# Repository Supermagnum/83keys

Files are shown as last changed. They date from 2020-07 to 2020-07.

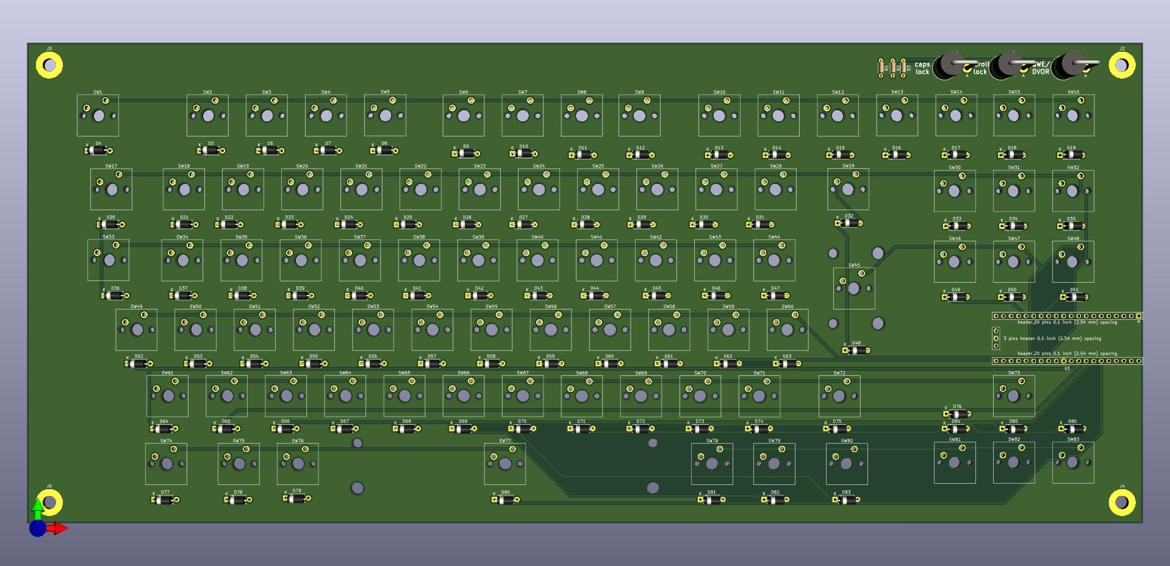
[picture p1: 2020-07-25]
Keyboard-ISO.jpg

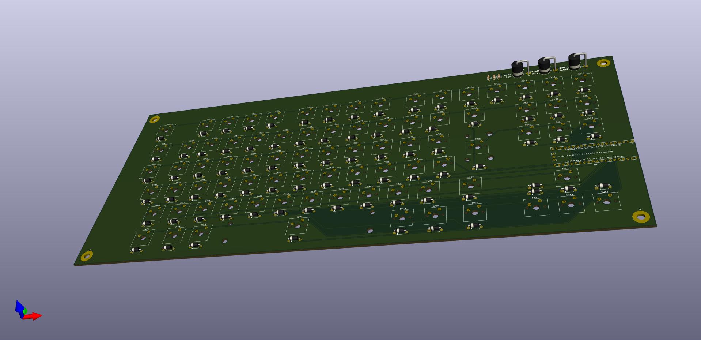
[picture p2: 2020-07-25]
Keyboard-ISO2.jpg

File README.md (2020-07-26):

# 83keys
A 83 key keyboard, Norwegian QWERTY/DVORAK ISO style.
It's of course possible to use other languages, as the MX cherry switches will accept keycaps with whatever language you need.

It uses 83 1N4148 diodes and three LED's for caps lock,scroll lock, and QWERTY/DVORAK.
It also needs pin headers that accepts the pins from a Teensy++2.0.

That makes it easy to replace the Teensy in the case that something goes wrong.
Since the Teensy++2.0 is mounted in a socket, there is no special training required because there are no need to solder any SMD components. 
I think that that makes it easier to mass produce because little training and special tools are required.

The keyboard layout is located here:
http://www.keyboard-layout-editor.com/#/gists/53284f72c23040b29def237b7399e567

Made using Kicad, that can be found here:
https://kicad-pcb.org/

All footprints for the components needed for the keyboard is included in this GitHub.
That excludes the Teensy++2.0 board and the components needed for it.

Kicad footprints for Teensy 
https://github.com/XenGi/teensy.pretty

Kicad schematic symbols of Teensy modules:
https://github.com/XenGi/teensy_library

QMK is here:
https://qmk.fm/

The handwire folder contains files necessary to make the bottom,top and switch plates for those who want to handwire the keyboard without using a PCB.
It should be compatible with Cherry Stabilizers. 

I hope that the Teensy socket is wired up correctly.
If not,please fork this repository and make the required changes.

Note: The diodes on the schematic diagram is wrong.

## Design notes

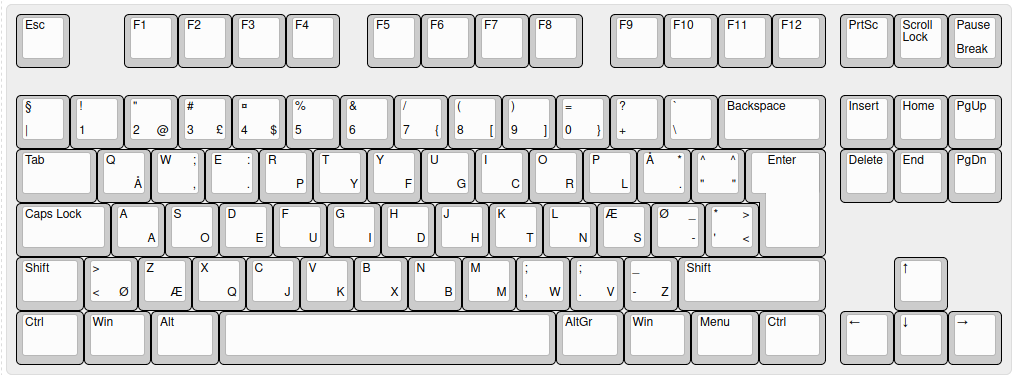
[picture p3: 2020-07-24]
layout.png

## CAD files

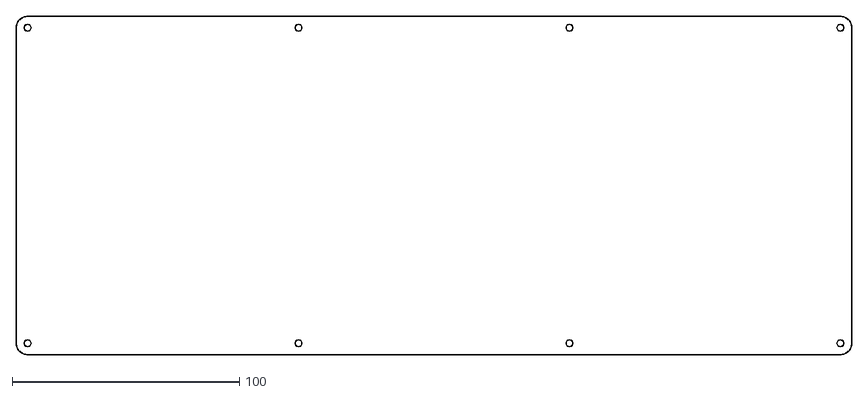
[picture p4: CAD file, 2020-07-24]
handwire/Plate_bottom.dxf
367.7 x 148.8

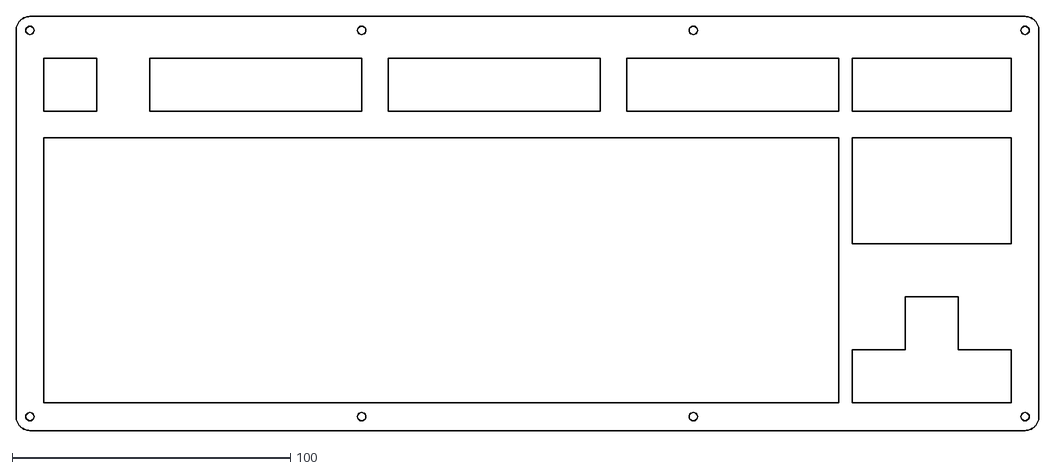
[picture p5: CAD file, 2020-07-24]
handwire/top.dxf
367.7 x 148.8

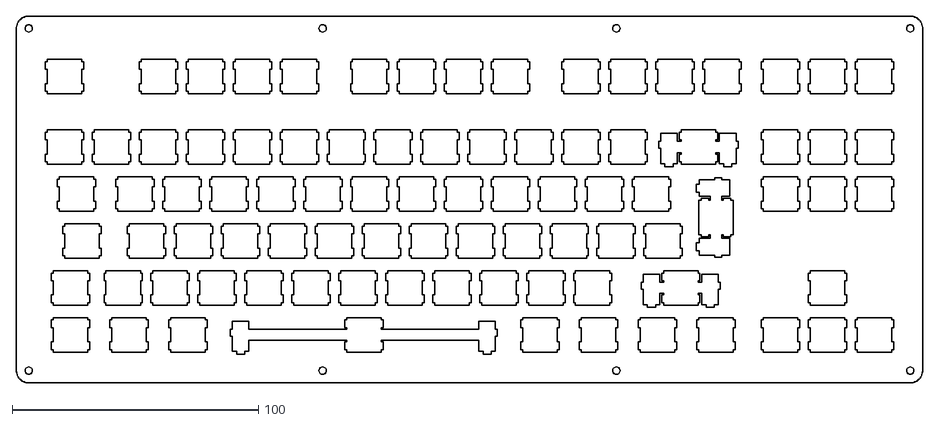
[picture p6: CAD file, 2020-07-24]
handwire/Plate_switch.dxf
367.7 x 148.8

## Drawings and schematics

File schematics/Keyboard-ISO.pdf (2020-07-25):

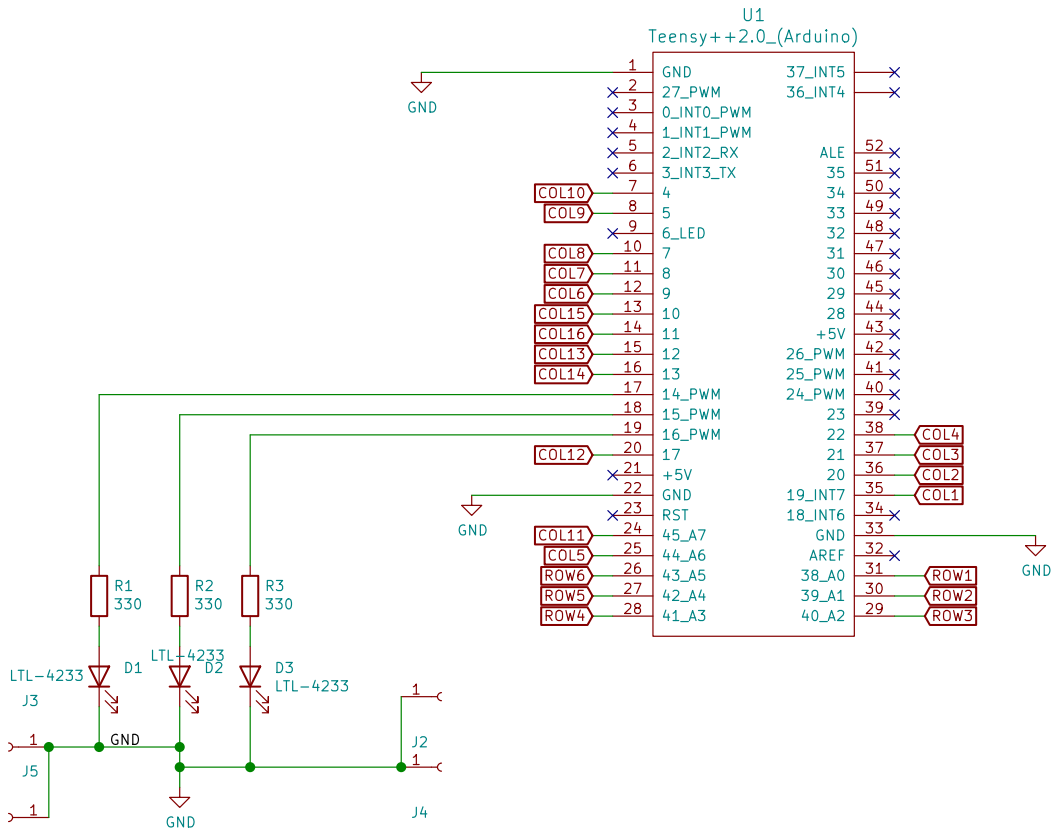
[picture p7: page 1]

File: Keyboard-ISO.sch Sheet: / Sheet: matrix

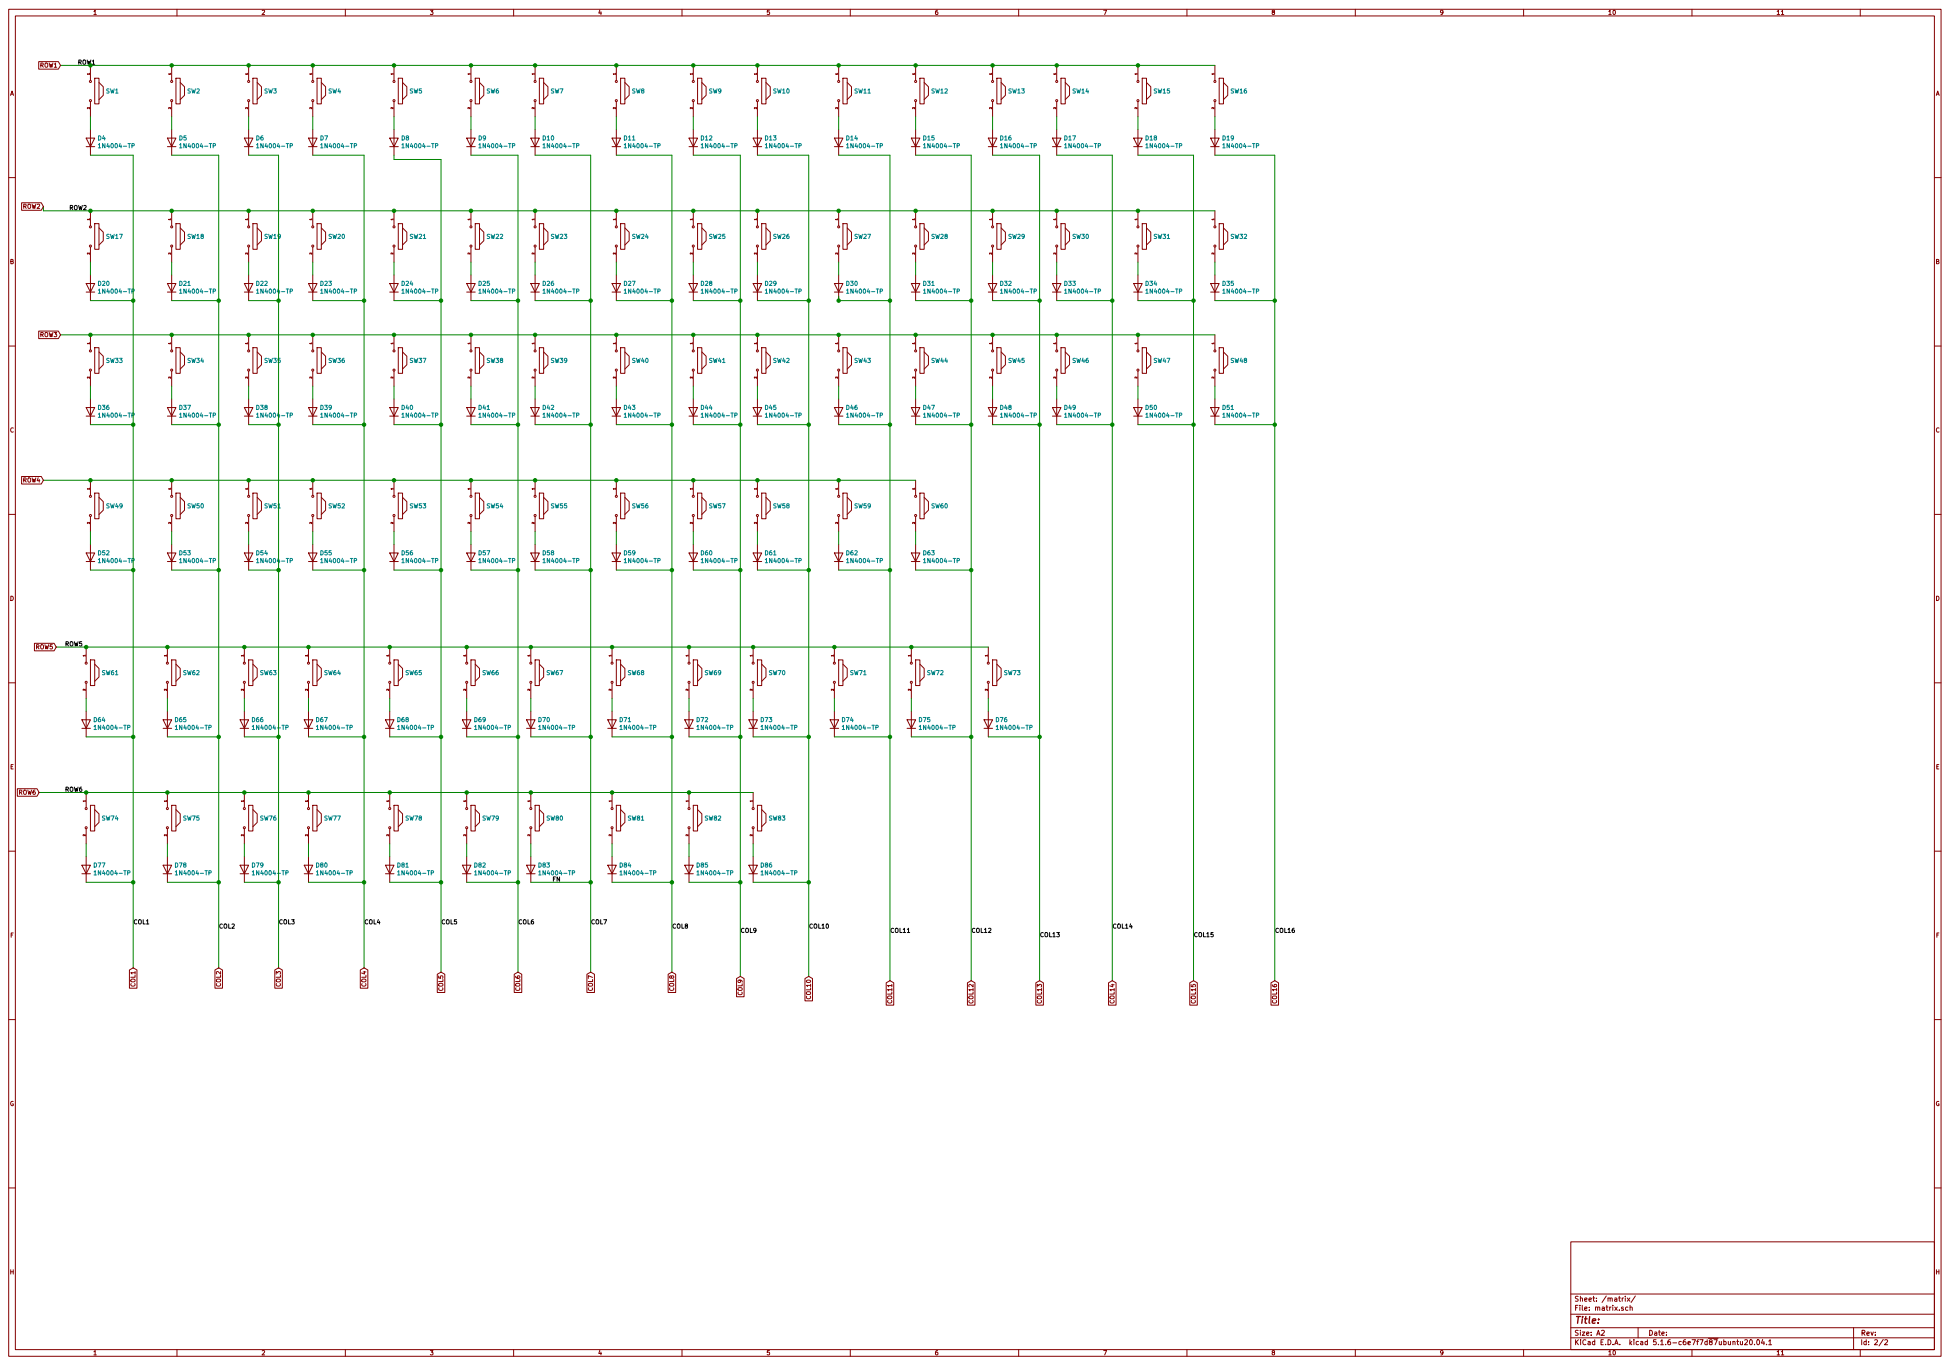
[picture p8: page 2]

Id: 2/2 Title: File: matrix.sch Sheet: /matrix/

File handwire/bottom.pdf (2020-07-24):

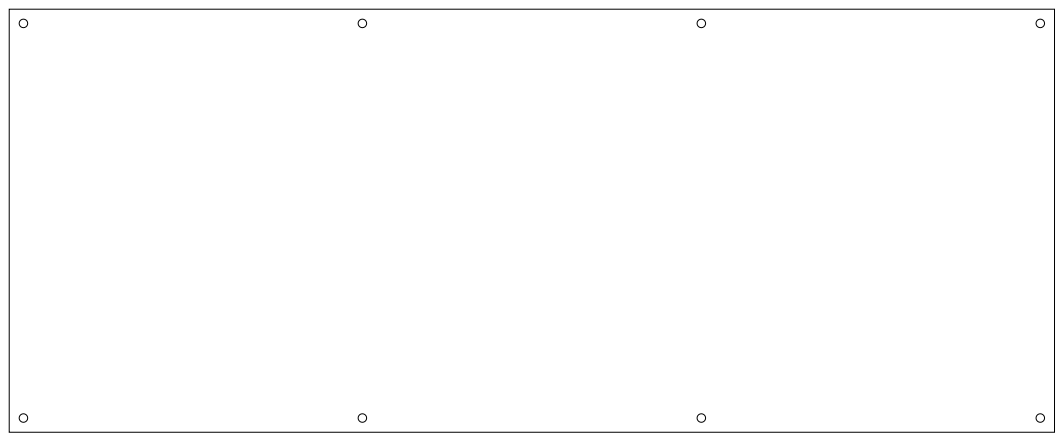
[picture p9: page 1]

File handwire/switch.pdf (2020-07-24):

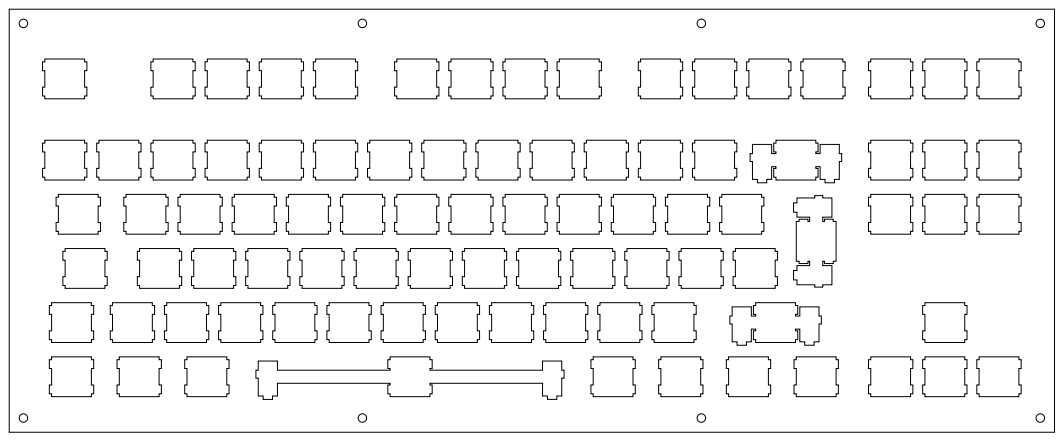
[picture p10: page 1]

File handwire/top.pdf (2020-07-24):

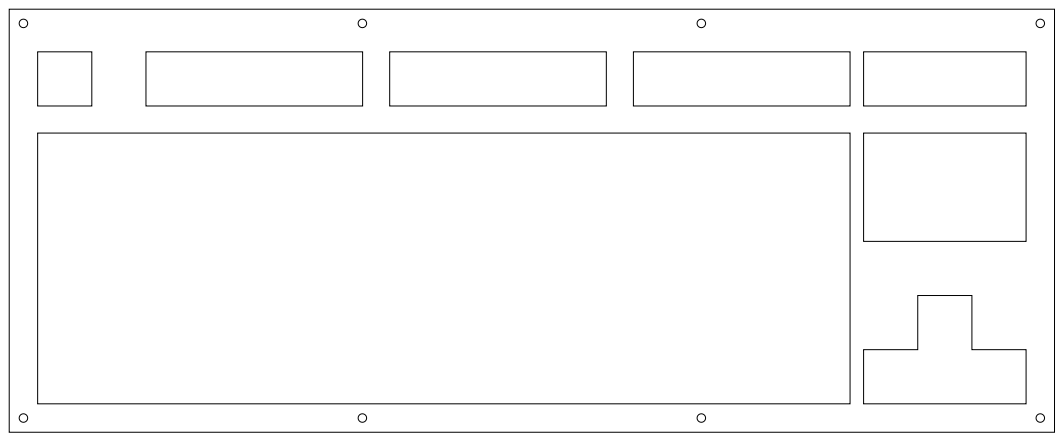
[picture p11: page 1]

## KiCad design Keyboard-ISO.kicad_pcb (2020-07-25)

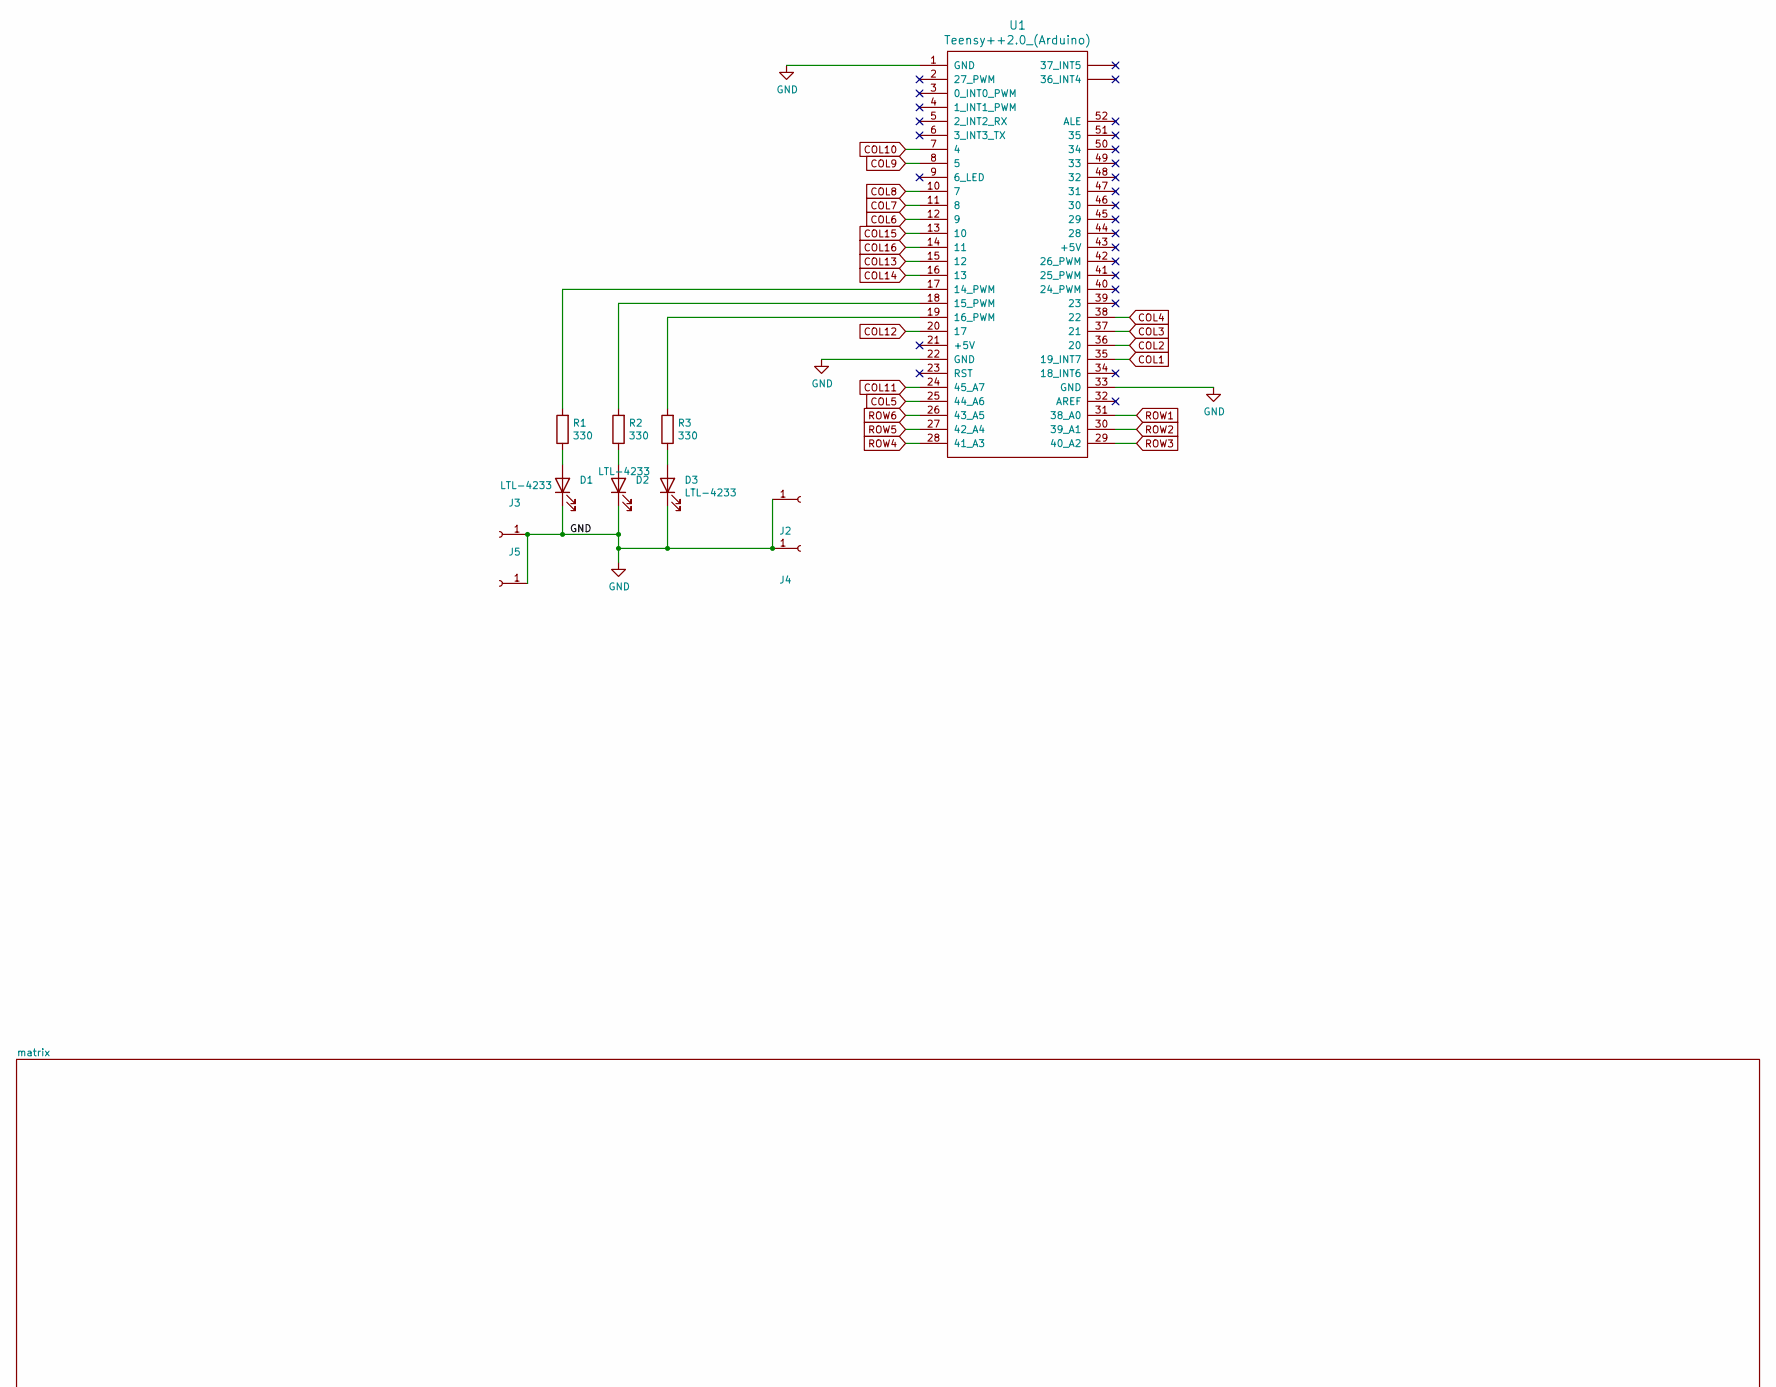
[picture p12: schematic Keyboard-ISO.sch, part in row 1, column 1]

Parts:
D1, D2, D3: LTL-4233; D_5KPW_P7.62mm_Vertical_AnodeUp
J2, J3, J4, J5: Conn_01x01_Female; MountingHole_4.5mm_Pad
R1, R2, R3: 330; R_Axial_DIN0204_L3.6mm_D1.6mm_P5.08mm_Horizontal
U1: Teensy++2.0_(Arduino); Teensy2.0-pins-headers

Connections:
COL1: U1.35 (19_INT7); also elsewhere on the board
COL2: U1.36 (20); also elsewhere on the board
COL3: U1.37 (21); also elsewhere on the board
COL4: U1.38 (22); also elsewhere on the board
COL5: U1.25 (44_A6); also elsewhere on the board
COL6: U1.12 (9); also elsewhere on the board
COL7: U1.11 (8); also elsewhere on the board
COL8: U1.10 (7); also elsewhere on the board
COL9: U1.8 (5); also elsewhere on the board
COL10: U1.7 (4); also elsewhere on the board
COL11: U1.24 (45_A7); also elsewhere on the board
COL12: U1.20 (17); also elsewhere on the board
COL13: U1.15 (12); also elsewhere on the board
COL14: U1.16 (13); also elsewhere on the board
COL15: U1.13 (10); also elsewhere on the board
COL16: U1.14 (11); also elsewhere on the board
GND: D1.1 (K), D2.1 (K), D3.1 (K), J2.1, J3.1, J4.1, J5.1, U1.1 (GND), U1.22 (GND), U1.33 (GND)
unnamed: D1.2 (A), R1.1
unnamed: D2.2 (A), R2.1
unnamed: D3.2 (A), R3.1
unnamed: R1.2, U1.17 (14_PWM)
unnamed: R2.2, U1.18 (15_PWM)
unnamed: R3.2, U1.19 (16_PWM)
ROW1: U1.31 (38_A0); also elsewhere on the board
ROW2: U1.30 (39_A1); also elsewhere on the board
ROW3: U1.29 (40_A2); also elsewhere on the board
ROW4: U1.28 (41_A3); also elsewhere on the board
ROW5: U1.27 (42_A4); also elsewhere on the board
ROW6: U1.26 (43_A5); also elsewhere on the board

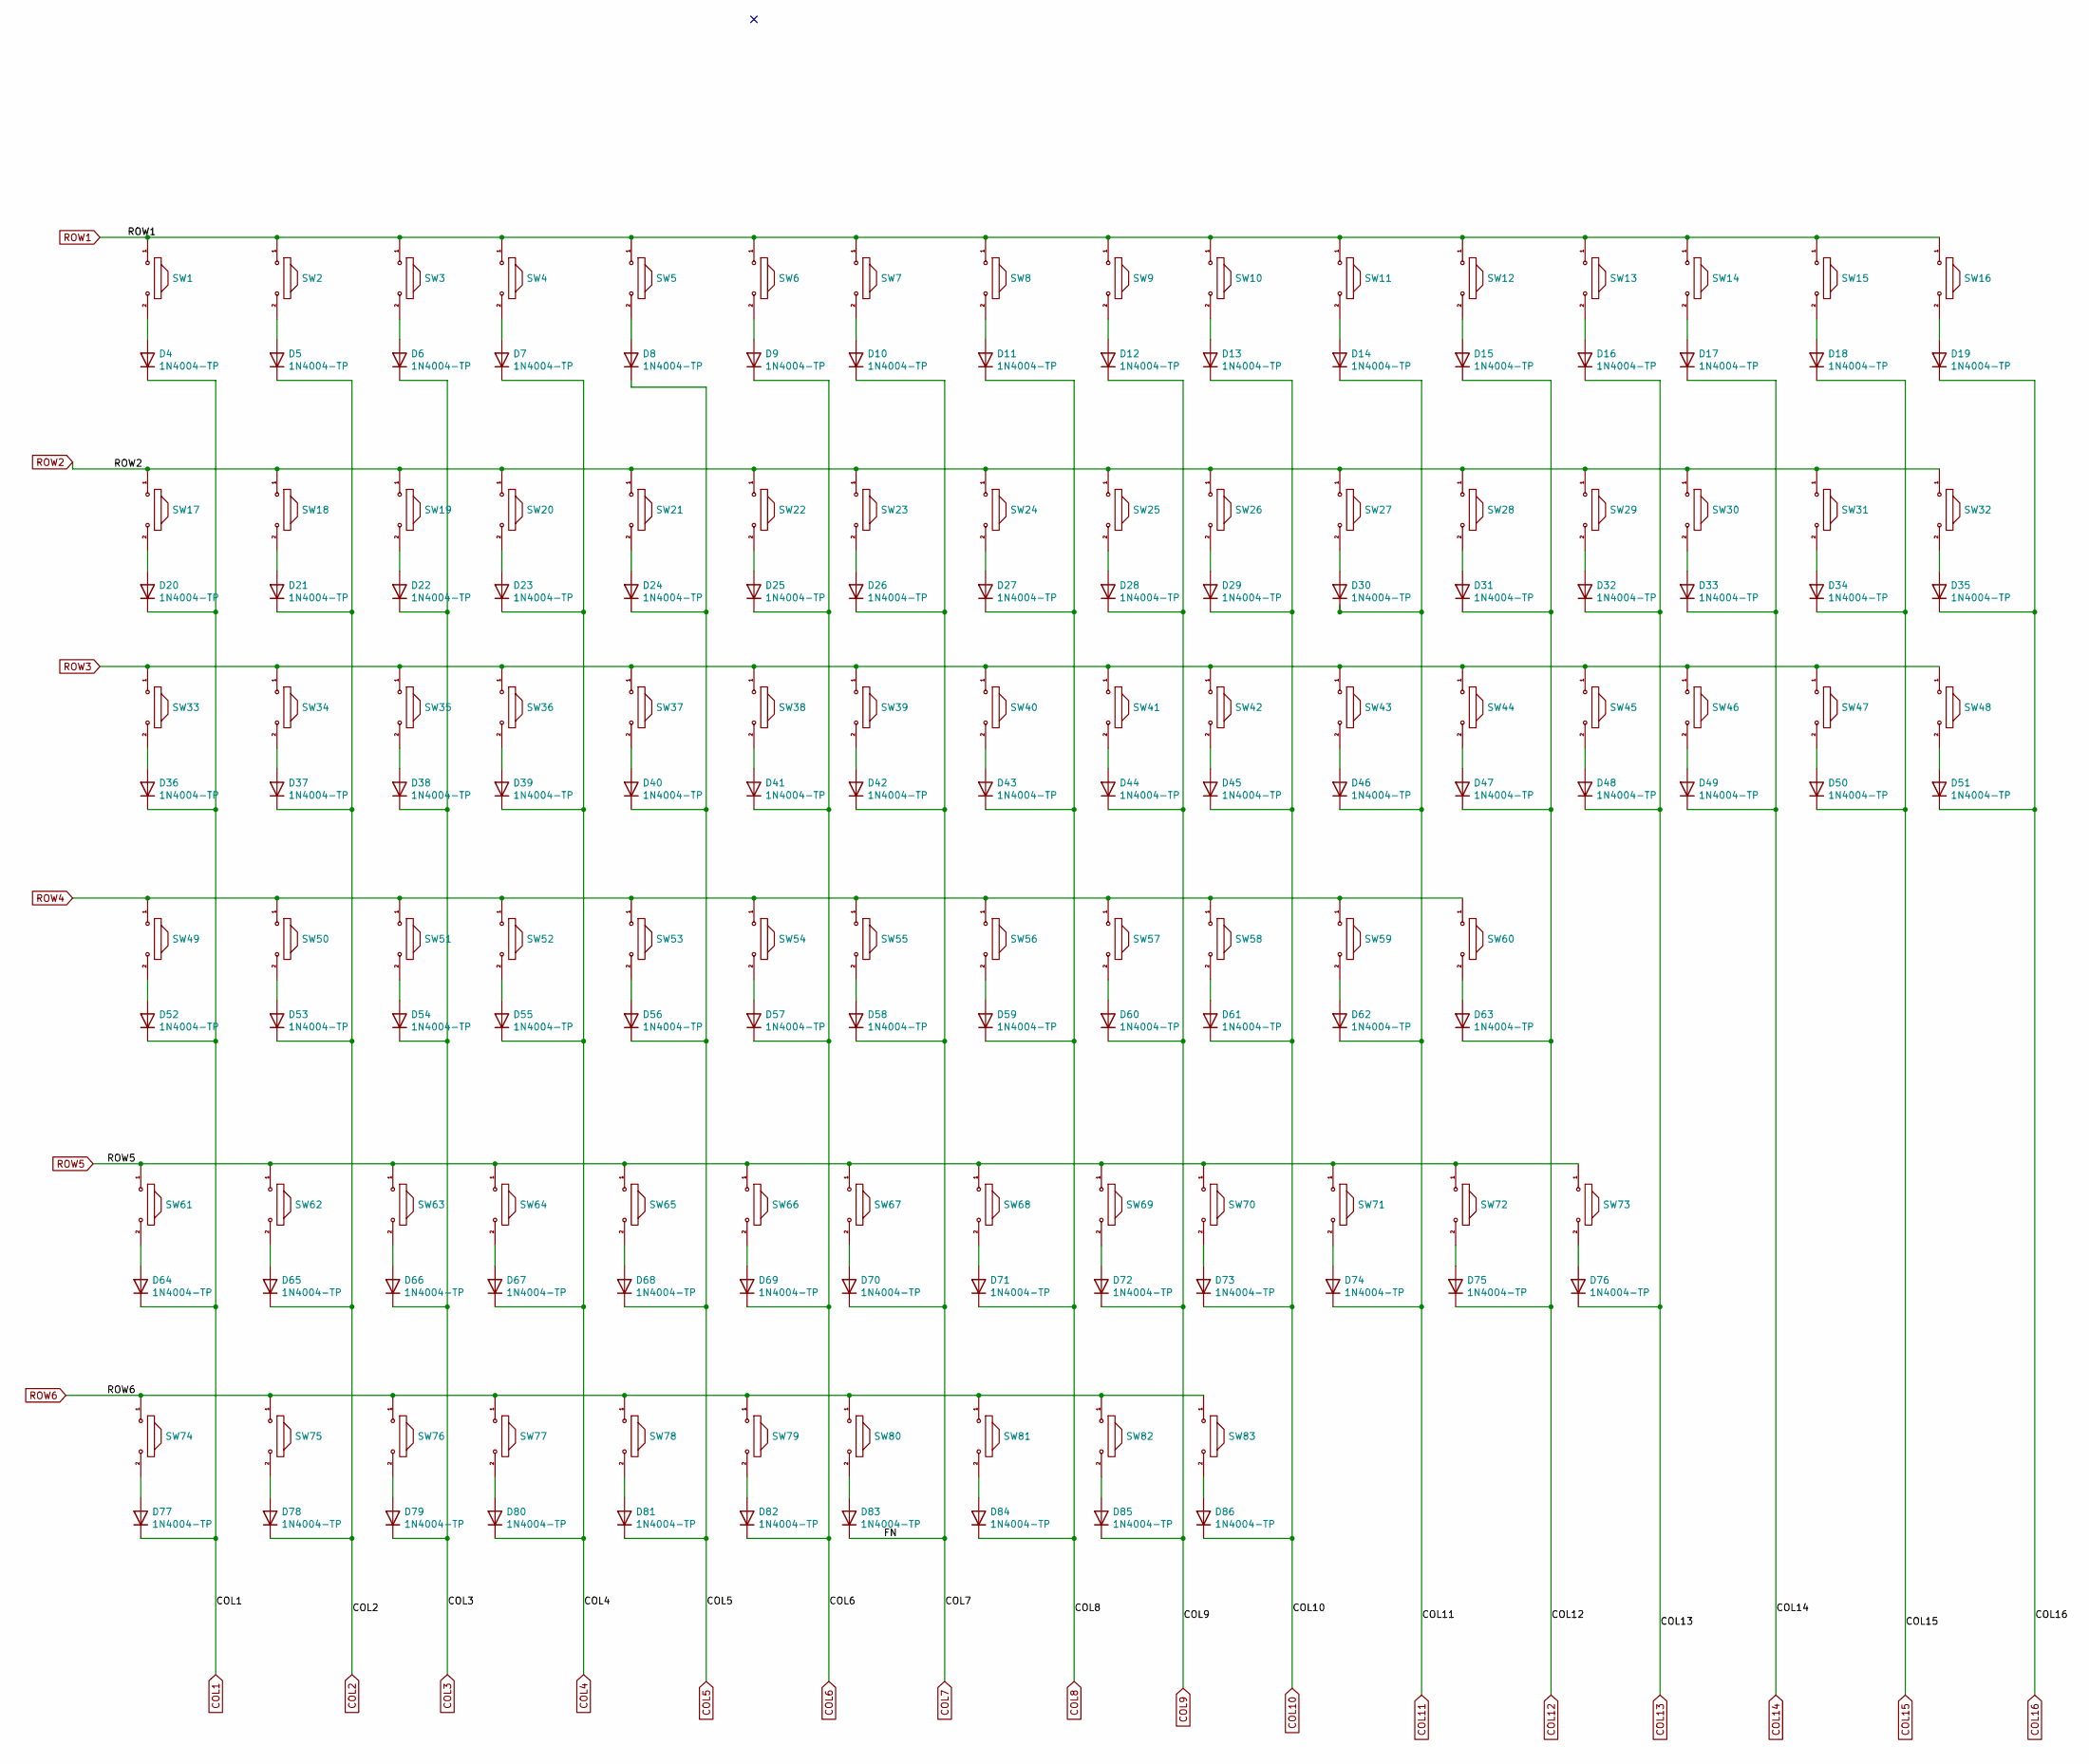
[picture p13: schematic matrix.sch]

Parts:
D4, D5, D6, D7, D8, D9, D10, D11, D12, D13, D14, D15, D16, D17, D18, D19, D20, D21, D22, D23, D24, D25, D26, D27, D28, D29, D30, D31, D32, D33, D34, D35, D36, D37, D38, D39, D40, D41, D42, D43, D44, D45, D46, D47, D48, D49, D50, D51, D52, D53, D54, D55, D56, D57, D58, D59, D60, D61, D62, D63, D64, D65, D66, D67, D68, D69, D70, D71, D72, D73, D74, D75, D76, D77, D78, D79, D80, D81, D82, D83, D84, D85, D86: 1N4004-TP; D_A-405_P7.62mm_Horizontal
SW1, SW2, SW3, SW4, SW5, SW6, SW7, SW8, SW9, SW10, SW11, SW12, SW13, SW14, SW15, SW16, SW19, SW20, SW21, SW22, SW23, SW24, SW25, SW26, SW27, SW28, SW31, SW32, SW35, SW36, SW37, SW38, SW39, SW40, SW41, SW42, SW43, SW44, SW46, SW47, SW48, SW49, SW50, SW51, SW52, SW53, SW54, SW55, SW56, SW57, SW58, SW59, SW60, SW61, SW62, SW63, SW64, SW65, SW66, SW67, SW68, SW69, SW70, SW71, SW76, SW79, SW82, SW83: MX; SW_Cherry_MX_1.00u_PCB-NO-LED
SW17, SW29, SW33, SW74, SW80: SW_Cherry_MX_1.50u_PCB
SW18, SW30, SW34, SW73, SW75, SW78, SW81: MX; SW_Cherry_MX_1.00u_PCB
SW45: MX; SW_Cherry_MX_ISOEnter_PCB
SW72: MX; SW_Cherry_MX_1.75u_PCB
SW77: SW_Cherry_MX_6.26u_PCB; SW_Cherry_MX_6.25u_PCB

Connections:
COL1: D4.1 (K), D20.1 (K), D36.1 (K), D52.1 (K), D64.1 (K), D77.1 (K); also elsewhere on the board
COL2: D5.1 (K), D21.1 (K), D37.1 (K), D53.1 (K), D65.1 (K), D78.1 (K); also elsewhere on the board
COL3: D6.1 (K), D22.1 (K), D38.1 (K), D54.1 (K), D66.1 (K), D79.1 (K); also elsewhere on the board
COL4: D7.1 (K), D23.1 (K), D39.1 (K), D55.1 (K), D67.1 (K), D80.1 (K); also elsewhere on the board
COL5: D8.1 (K), D24.1 (K), D40.1 (K), D56.1 (K), D68.1 (K), D81.1 (K); also elsewhere on the board
COL6: D9.1 (K), D25.1 (K), D41.1 (K), D57.1 (K), D69.1 (K), D82.1 (K); also elsewhere on the board
COL7: D10.1 (K), D26.1 (K), D42.1 (K), D58.1 (K), D70.1 (K), D83.1 (K); also elsewhere on the board
COL8: D11.1 (K), D27.1 (K), D43.1 (K), D59.1 (K), D71.1 (K), D84.1 (K); also elsewhere on the board
COL9: D12.1 (K), D28.1 (K), D44.1 (K), D60.1 (K), D72.1 (K), D85.1 (K); also elsewhere on the board
COL10: D13.1 (K), D29.1 (K), D45.1 (K), D61.1 (K), D73.1 (K), D86.1 (K); also elsewhere on the board
COL11: D14.1 (K), D30.1 (K), D46.1 (K), D62.1 (K), D74.1 (K); also elsewhere on the board
COL12: D15.1 (K), D31.1 (K), D47.1 (K), D63.1 (K), D75.1 (K); also elsewhere on the board
COL13: D16.1 (K), D32.1 (K), D48.1 (K), D76.1 (K); also elsewhere on the board
COL14: D17.1 (K), D33.1 (K), D49.1 (K); also elsewhere on the board
COL15: D18.1 (K), D34.1 (K), D50.1 (K); also elsewhere on the board
COL16: D19.1 (K), D35.1 (K), D51.1 (K); also elsewhere on the board
unnamed: D4.2 (A), SW1.2
unnamed: D5.2 (A), SW2.2
unnamed: D6.2 (A), SW3.2
unnamed: D7.2 (A), SW4.2
unnamed: D8.2 (A), SW5.2
unnamed: D9.2 (A), SW6.2
unnamed: D10.2 (A), SW7.2
unnamed: D11.2 (A), SW8.2
unnamed: D12.2 (A), SW9.2
unnamed: D13.2 (A), SW10.2
unnamed: D14.2 (A), SW11.2
unnamed: D15.2 (A), SW12.2
unnamed: D16.2 (A), SW13.2
unnamed: D17.2 (A), SW14.2
unnamed: D18.2 (A), SW15.2
unnamed: D19.2 (A), SW16.2
unnamed: D20.2 (A), SW17.2
unnamed: D21.2 (A), SW18.2
unnamed: D22.2 (A), SW19.2
unnamed: D23.2 (A), SW20.2
unnamed: D24.2 (A), SW21.2
unnamed: D25.2 (A), SW22.2
unnamed: D26.2 (A), SW23.2
unnamed: D27.2 (A), SW24.2
unnamed: D28.2 (A), SW25.2
unnamed: D29.2 (A), SW26.2
unnamed: D30.2 (A), SW27.2
unnamed: D31.2 (A), SW28.2
unnamed: D32.2 (A), SW29.2
unnamed: D33.2 (A), SW30.2
unnamed: D34.2 (A), SW31.2
unnamed: D35.2 (A), SW32.2
unnamed: D36.2 (A), SW33.2
unnamed: D37.2 (A), SW34.2
unnamed: D38.2 (A), SW35.2
unnamed: D39.2 (A), SW36.2
unnamed: D40.2 (A), SW37.2
unnamed: D41.2 (A), SW38.2
unnamed: D42.2 (A), SW39.2
unnamed: D43.2 (A), SW40.2
unnamed: D44.2 (A), SW41.2
unnamed: D45.2 (A), SW42.2
unnamed: D46.2 (A), SW43.2
unnamed: D47.2 (A), SW44.2
unnamed: D48.2 (A), SW45.2
unnamed: D49.2 (A), SW46.2
unnamed: D50.2 (A), SW47.2
unnamed: D51.2 (A), SW48.2
unnamed: D52.2 (A), SW49.2
unnamed: D53.2 (A), SW50.2
unnamed: D54.2 (A), SW51.2
unnamed: D55.2 (A), SW52.2
unnamed: D56.2 (A), SW53.2
unnamed: D57.2 (A), SW54.2
unnamed: D58.2 (A), SW55.2
unnamed: D59.2 (A), SW56.2
unnamed: D60.2 (A), SW57.2
unnamed: D61.2 (A), SW58.2
unnamed: D62.2 (A), SW59.2
unnamed: D63.2 (A), SW60.2
unnamed: D64.2 (A), SW61.2
unnamed: D65.2 (A), SW62.2
unnamed: D66.2 (A), SW63.2
unnamed: D67.2 (A), SW64.2
unnamed: D68.2 (A), SW65.2
unnamed: D69.2 (A), SW66.2
unnamed: D70.2 (A), SW67.2
unnamed: D71.2 (A), SW68.2
unnamed: D72.2 (A), SW69.2
unnamed: D73.2 (A), SW70.2
unnamed: D74.2 (A), SW71.2
unnamed: D75.2 (A), SW72.2
unnamed: D76.2 (A), SW73.2
unnamed: D77.2 (A), SW74.2
unnamed: D78.2 (A), SW75.2
unnamed: D79.2 (A), SW76.2
unnamed: D80.2 (A), SW77.2
unnamed: D81.2 (A), SW78.2
unnamed: D82.2 (A), SW79.2
unnamed: D83.2 (A), SW80.2
unnamed: D84.2 (A), SW81.2
unnamed: D85.2 (A), SW82.2
unnamed: D86.2 (A), SW83.2
ROW1: SW1.1, SW2.1, SW3.1, SW4.1, SW5.1, SW6.1, SW7.1, SW8.1, SW9.1, SW10.1, SW11.1, SW12.1, SW13.1, SW14.1, SW15.1, SW16.1; also elsewhere on the board
ROW2: SW17.1, SW18.1, SW19.1, SW20.1, SW21.1, SW22.1, SW23.1, SW24.1, SW25.1, SW26.1, SW27.1, SW28.1, SW29.1, SW30.1, SW31.1, SW32.1; also elsewhere on the board
ROW3: SW33.1, SW34.1, SW35.1, SW36.1, SW37.1, SW38.1, SW39.1, SW40.1, SW41.1, SW42.1, SW43.1, SW44.1, SW45.1, SW46.1, SW47.1, SW48.1; also elsewhere on the board
ROW4: SW49.1, SW50.1, SW51.1, SW52.1, SW53.1, SW54.1, SW55.1, SW56.1, SW57.1, SW58.1, SW59.1, SW60.1; also elsewhere on the board
ROW5: SW61.1, SW62.1, SW63.1, SW64.1, SW65.1, SW66.1, SW67.1, SW68.1, SW69.1, SW70.1, SW71.1, SW72.1, SW73.1; also elsewhere on the board
ROW6: SW74.1, SW75.1, SW76.1, SW77.1, SW78.1, SW79.1, SW80.1, SW81.1, SW82.1, SW83.1; also elsewhere on the board

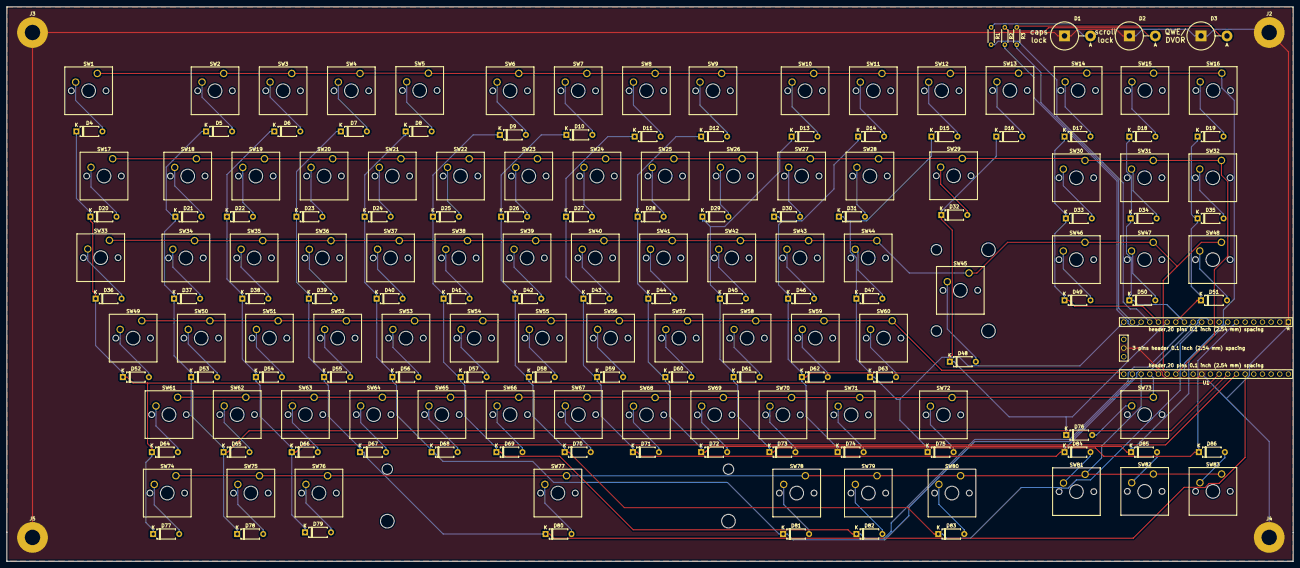
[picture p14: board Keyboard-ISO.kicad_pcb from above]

Board: 2 copper layers, 377.0 x 162.5 mm, 177 parts (0 on the bottom side), 112 nets.

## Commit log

2020-07-23 added more files,and footprint library
    [Keyboard-ISO-B_Adhes.gbr, Keyboard-ISO-B_Cu.gbr, Keyboard-ISO-B_Mask.gbr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]
2020-07-24 Add files via upload
    Added files necessary for laser cutting and wiring by hand, without a PCB.
    [Plate_bottom.dxf, Plate_switch.dxf, top.dxf]
2020-07-24 Add files via upload
    Added pdf drawings, switch mount,top and bottom.
2020-07-24 Add files via upload
    updated files, and added pictures of PCB and key layouts
    [Keyboard-ISO-B_Adhes.gbr, Keyboard-ISO-B_Cu.gbr, Keyboard-ISO-B_Mask.gbr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]
2020-07-24 Add files via upload
    updated files
    [Keyboard-ISO-B_Adhes.gbr, Keyboard-ISO-B_Cu.gbr, Keyboard-ISO-B_Mask.gbr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]
2020-07-24 Add files via upload
    updated files.
    [Keyboard-ISO.dsn, Keyboard-ISO.kicad_pcb, matrix.sch]
2020-07-25 updated files
    Updated files, changed to using a Teensy++2.0 that plugs right in to the board
    [Keyboard-ISO-B_Adhes.gbr, Keyboard-ISO-B_Cu.gbr, Keyboard-ISO-B_Mask.gbr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]
2020-07-26 Update README.md
    Changed to faster diodes.
2020-07-26 Update Keyboard-ISO-BOM.html
    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
2020-07-27 updated gerber files.
    Moved the Teensy++2.0 headers to the backside of the board.
    [Keyboard-ISO-B_Adhes.gbr, Keyboard-ISO-B_Cu.gbr, Keyboard-ISO-B_Mask.gbr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]
2020-07-30 Add files via upload
    updated gerber files, removed unwanted empty zones.
    [Keyboard-ISO-B_Adhes.gbr, Keyboard-ISO-B_Cu.gbr, Keyboard-ISO-B_Mask.gbr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]
